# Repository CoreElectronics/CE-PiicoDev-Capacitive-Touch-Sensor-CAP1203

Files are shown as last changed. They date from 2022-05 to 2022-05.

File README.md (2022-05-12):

# PiicoDev® Capacitive Touch Sensor CAP1203

This is the repo for the Core Electronics [PiicoDev Capacitive Touch Sensor CAP1203](https://core-electronics.com.au/catalog/product/view/sku/CE07816).

PiicoDev Capacitive Touch Sensor by Core Electronics

The PiicoDev® Capacitive Touch Sensor gives your project three touch pads to use as inputs. This is an effective way to introduce control inputs to your project.  Get creative and use other items as touch plates using PCB headers or the alligator clip connection holes.

- 3 Capacitive Touch Sensor inputs
- Supports simultaneous touch events
- Programmable sensitivity
- Automatically calibrates at powerup
- Activity LED shows interrupt events
- PiicoDev connector, compatible with Qwiic and STEMMA QT (3.3V only)
- 2.54mm breakout for breadboarding/prototyping
- Manufactured and supported in Australia by Core Electronics

Getting Started Guides

- For [Micro:bit](https://core-electronics.com.au/tutorials/raspberry-pi-pico/piicodev-capacitive-touch-sensor-cap1203-micro-bit-guide.html)
- For [Raspberry Pi Pico](https://core-electronics.com.au/tutorials/raspberry-pi-pico/piicodev-capacitive-touch-sensor-cap1203-raspberry-pi-pico-guide.html)
- For [Raspberry Pi](https://core-electronics.com.au/tutorials/raspberry-pi-pico/piicodev-capacitive-touch-sensor-cap1203-raspberry-pi-guide.html)

# License
This project is open source - please review the LICENSE.md file for further licensing information.

If you have any technical questions, or concerns about licensing, please contact technical support on the [Core Electronics forums](https://forum.core-electronics.com.au/).

# Attribution
The hardware design of this module is influenced by the design from [Sparkfun](https://github.com/sparkfun/Qwiic_Capacitive_Touch_Slider_CAP1203).

*\"PiicoDev\" and the PiicoDev logo are trademarks of Core Electronics Pty Ltd.*

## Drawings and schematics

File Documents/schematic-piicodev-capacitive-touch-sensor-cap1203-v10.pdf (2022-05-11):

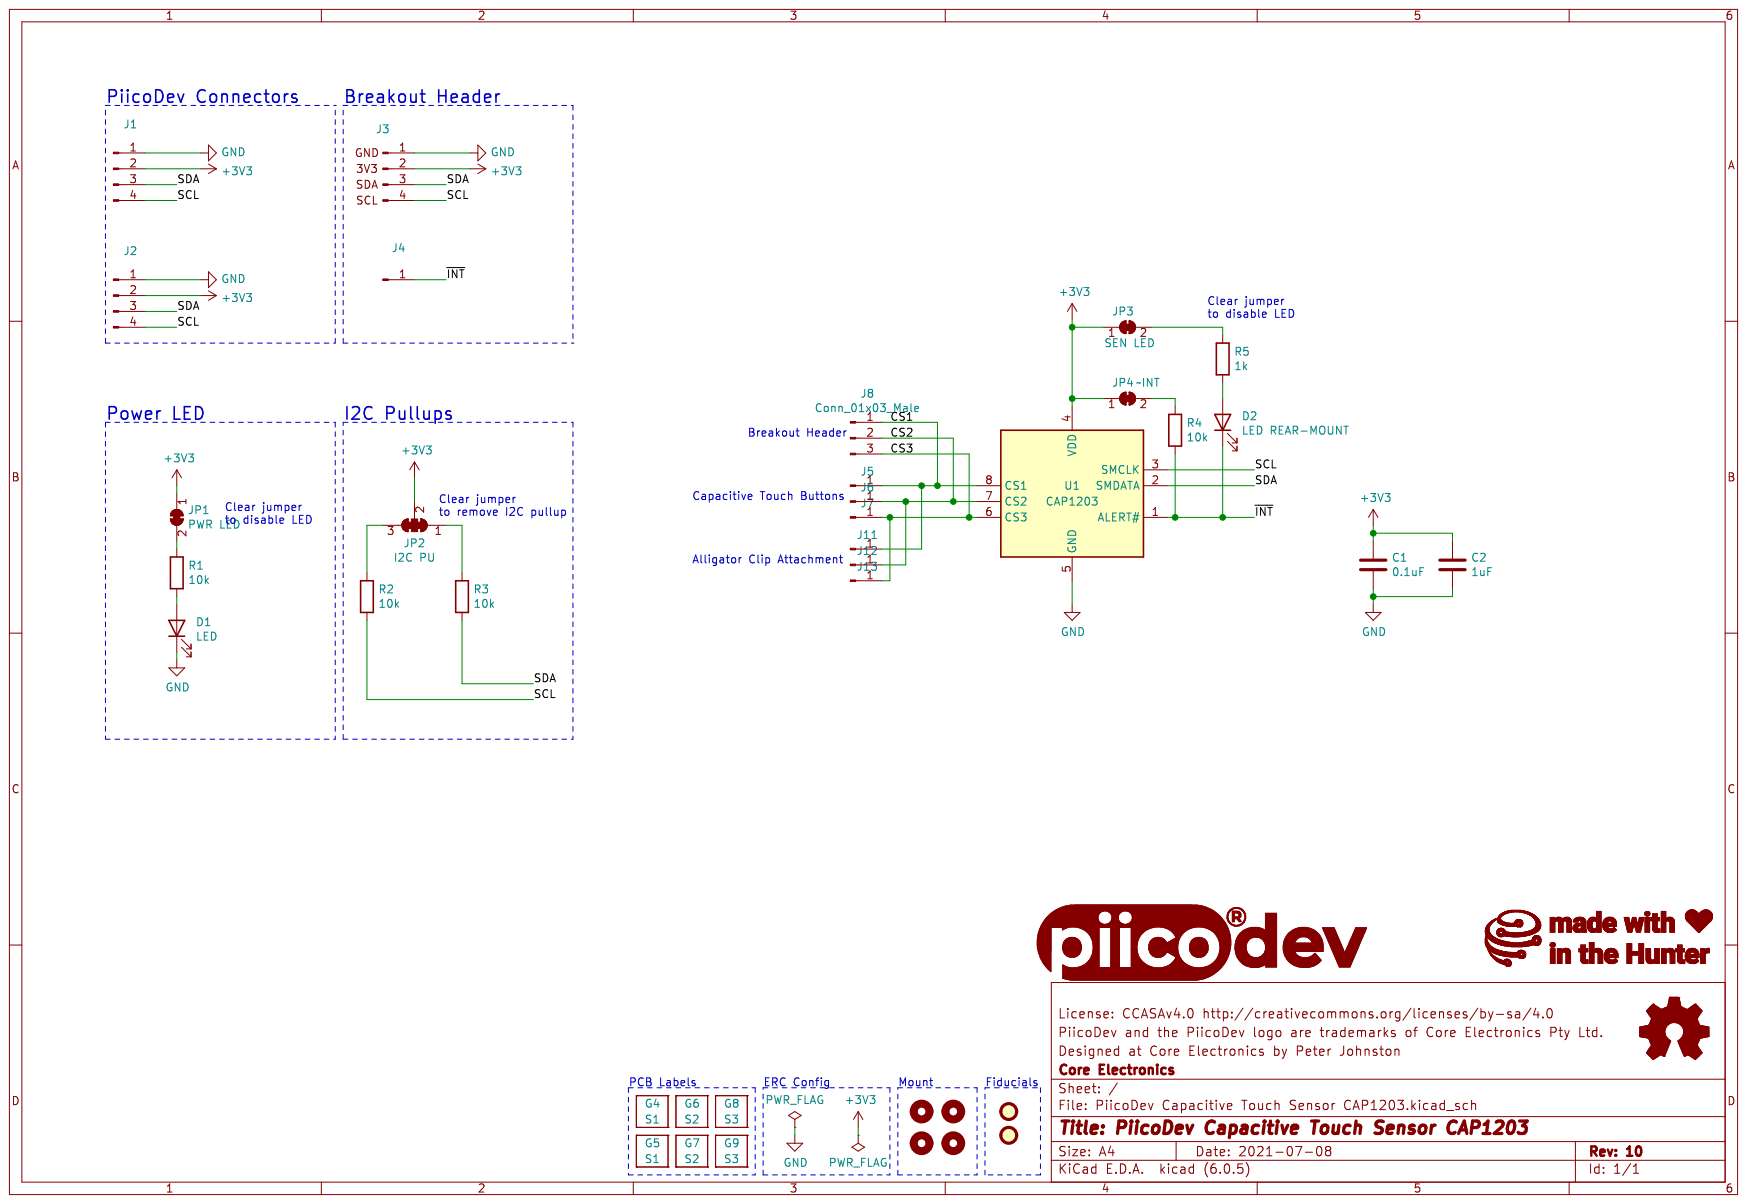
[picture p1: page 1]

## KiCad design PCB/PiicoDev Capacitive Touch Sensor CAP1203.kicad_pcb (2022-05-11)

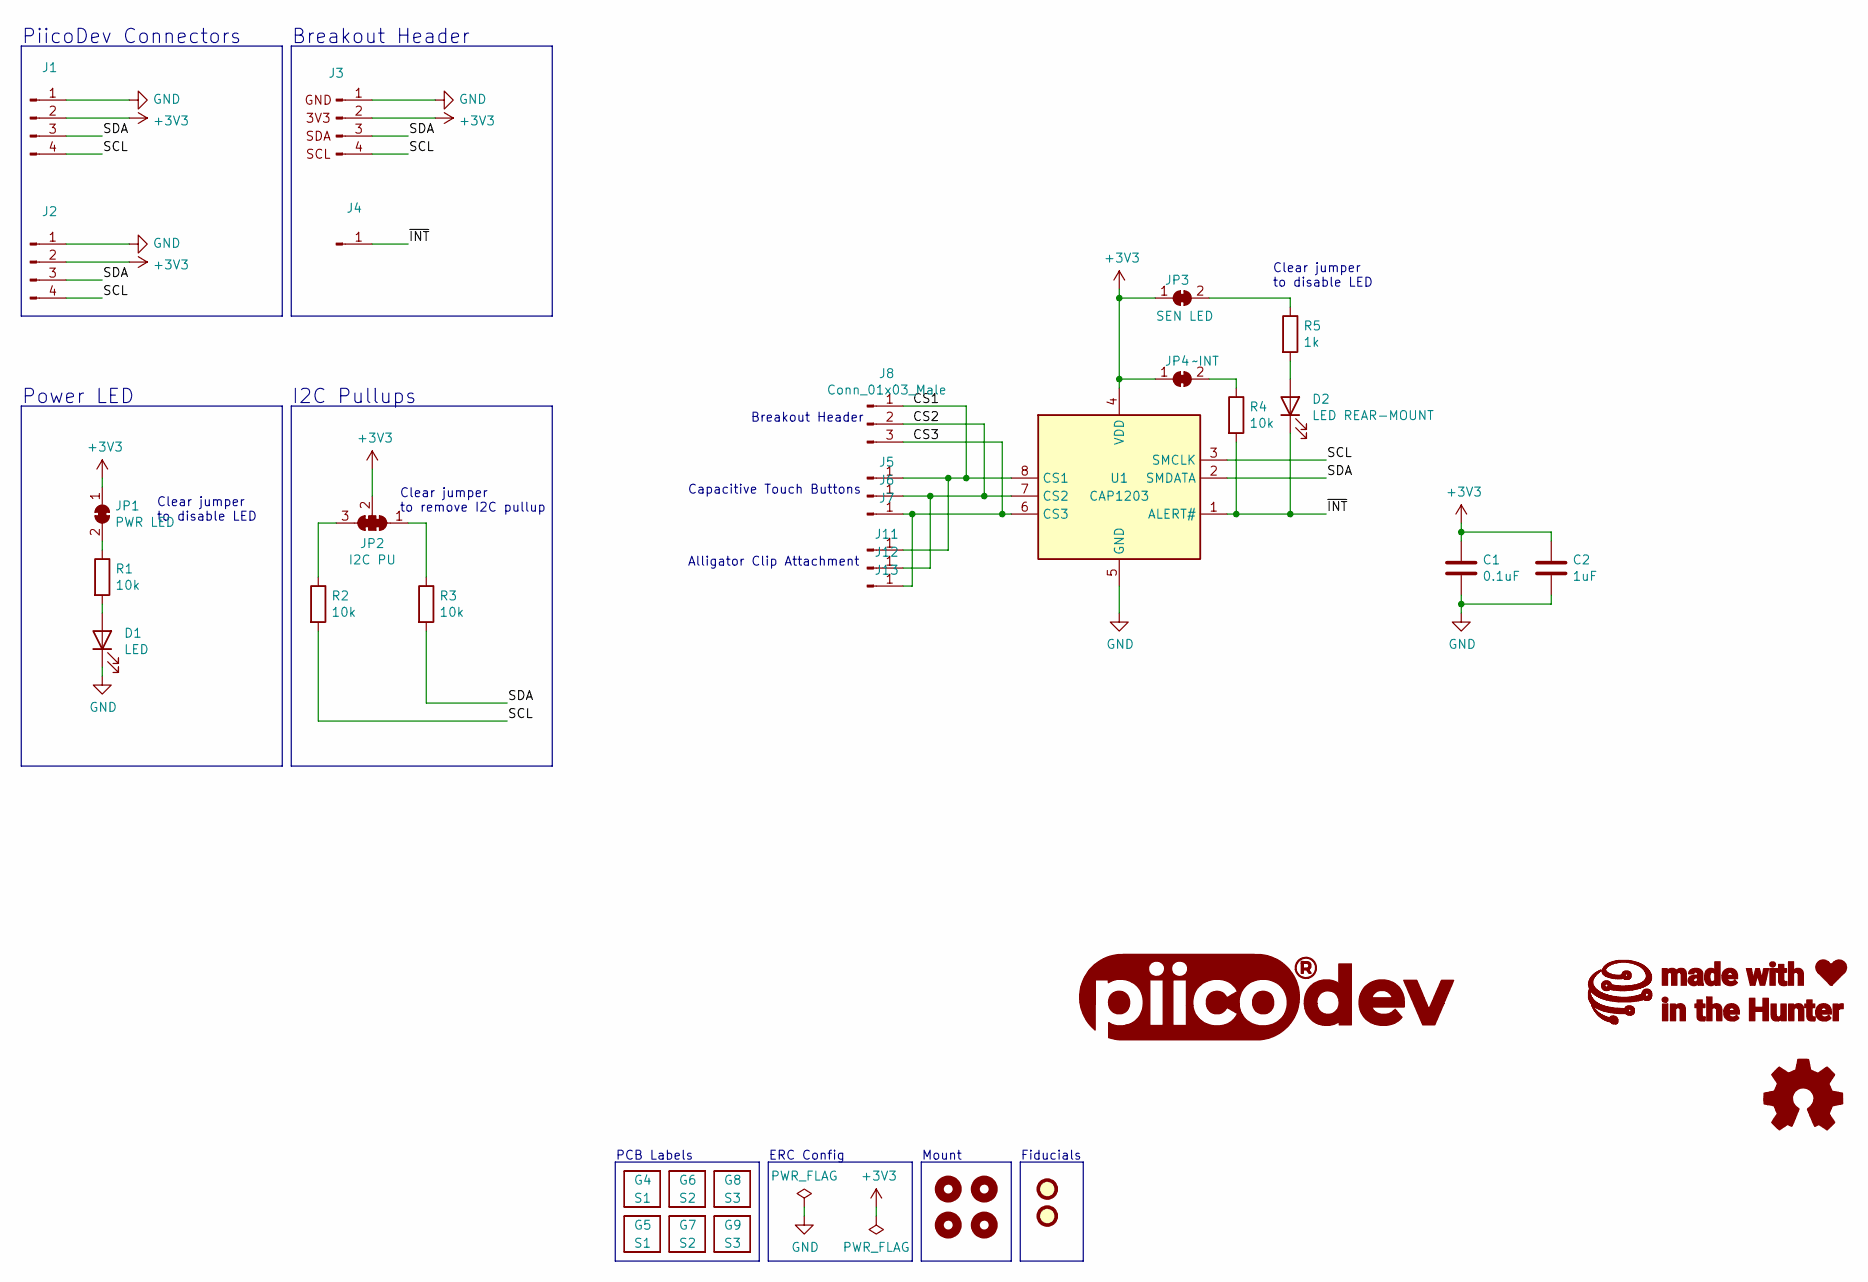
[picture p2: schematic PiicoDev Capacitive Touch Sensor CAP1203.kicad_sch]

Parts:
C1: 0.1uF; C_0402_1005Metric
C2: 1uF; C_0402_1005Metric
D1: LED; LED_0603_1608Metric
D2: LED REAR-MOUNT; LED_1206_3216Metric_ReverseMount_Hole1.8x2.4mm
FID1, FID2: Fiducial; Fiducial_1mm_Mask2mm
G1: LOGO_PiicoDev; piicodev_logo_14.2x3.4mm
G2: LOGO_CoreElectronics_no-text; CoreElectronics_logo_5mm
G3: LOGO_made-with-love; piicodev_logo_14.2x3.4mm
G4, G5: S1; Label_S1_Reverse
G6, G7: S2; Label_S2_Reverse
G8, G9: S3; Label_S3_Reverse
H1, H2, H3, H4: MountingHole; MountingHole_2.7mm_M2.5_PadClearance_1.2
J1, J2: JST_SH_SM04B-SRSS-TB_1x04-1MP_P1.00mm_Horizontal
J3: Conn_PiicoDev_header_01x04_Male; PiicoDev_header_4pin
J4: Conn_01x01_Male; PiicoDev_header_1pin_INT_inverted
J5, J6, J7: Conn_01x01_Male; Capacitive_Touch_Button
J8: Conn_01x03_Male; PinHeader_1x03_P2.54mm_Vertical
J11, J12, J13: Conn_01x01_Male; Conn_alligator
JP1: PWR LED; SolderJumper-2_P1.3mm_Bridged_RoundedPad1.0x1.5mm
JP2: I2C PU; SolderJumper-3_P1.3mm_Closed_RoundedPad1.0x1.5mm_NumberLabe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
JP3: SEN LED; SolderJumper-2_P1.3mm_Bridged_RoundedPad1.0x1.5mm
JP4: ~INT; SolderJumper-2_P1.3mm_Bridged_RoundedPad1.0x1.5mm
LOGO1: Logo_Open_Hardware_Small; oshw
R1, R2, R3, R4: 10k; R_0402_1005Metric
R5: 1k; R_0402_1005Metric
U1: CAP1203; SOIC-8_3.9x4.9mm_P1.27mm

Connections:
+3V3: C1.1, C2.1, J1.2, J2.2, J3.2, JP1.1 (A), JP2.2 (C), JP3.1 (A), JP4.1 (A), U1.4 (VDD)
/CS1: J5.1, J8.1, J11.1, U1.8 (CS1)
/CS2: J6.1, J8.2, J12.1, U1.7 (CS2)
/CS3: J7.1, J8.3, J13.1, U1.6 (CS3)
/SCL: J1.4, J2.4, J3.4, R2.2, U1.3 (SMCLK)
/SDA: J1.3, J2.3, J3.3, R3.2, U1.2 (SMDATA)
/~INT: D2.1 (K), J4.1, R4.2, U1.1 (ALERT#)
GND: C1.2, C2.2, D1.1 (K), J1.1, J2.1, J3.1, U1.5 (GND)
unnamed: D1.2 (A), R1.2
unnamed: D2.2 (A), R5.2
unnamed: JP1.2 (B), R1.1
unnamed: JP2.1 (A), R3.1
unnamed: JP2.3 (B), R2.1
unnamed: JP3.2 (B), R5.1
unnamed: JP4.2 (B), R4.1

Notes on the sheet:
Power LED
I2C Pullups
Capacitive Touch Buttons
Clear jumper to remove I2C pullup
Breakout Header
Alligator Clip Attachment
ERC Config
Mount
PCB Labels
PiicoDev Connectors
Clear jumper to disable LED
Fiducials

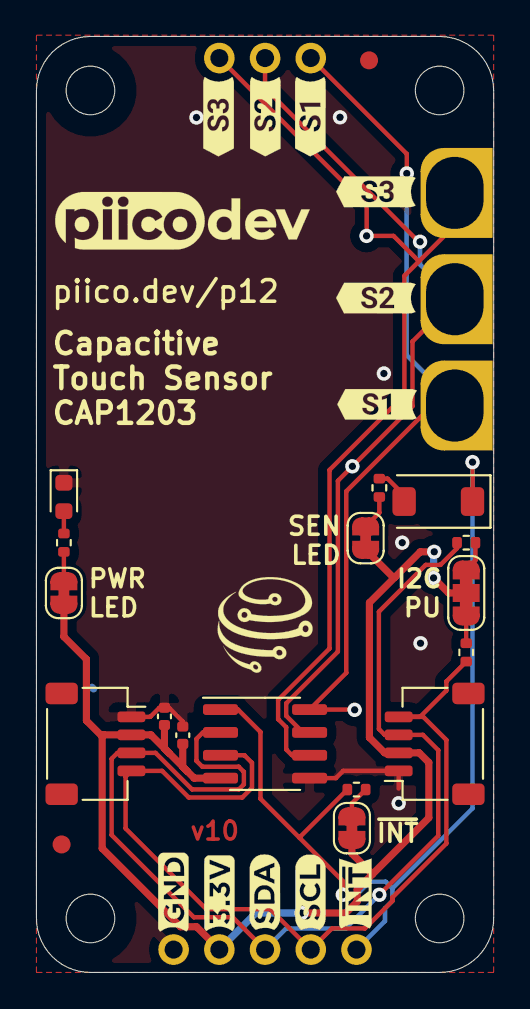
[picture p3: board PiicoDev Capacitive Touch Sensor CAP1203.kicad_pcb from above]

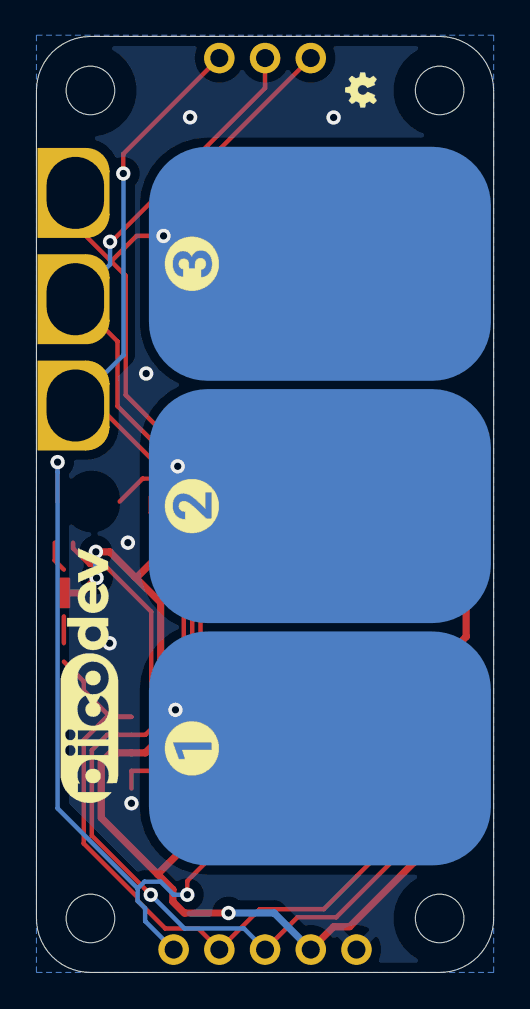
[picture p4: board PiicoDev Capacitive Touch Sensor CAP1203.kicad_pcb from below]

Board: 2 copper layers, 25.4 x 52.0 mm, 41 parts (7 on the bottom side), 15 nets.

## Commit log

2021-06-09 Update interrupt LED and increase alligator clip hole size
    [PiicoDev Capacitive Touch Sensor CAP1203.kicad_pcb, PiicoDev Capacitive Touch Sensor CAP1203.sch]
2021-06-21 Add silk screen labels
    [PiicoDev Capacitive Touch Sensor CAP1203.kicad_pcb, PiicoDev Capacitive Touch Sensor CAP1203.sch]
2021-06-23 Increase Alligator Clip Size
    [PiicoDev Capacitive Touch Sensor CAP1203.kicad_pcb, PiicoDev Capacitive Touch Sensor CAP1203.sch]
2021-06-24 Change top copper fill from grounded to floating sections
    [PiicoDev Capacitive Touch Sensor CAP1203.kicad_pcb, PiicoDev Capacitive Touch Sensor CAP1203.sch]
2021-07-08 Revert "Change top copper fill from grounded to floating sections"
    This reverts commit 368bc0d4ff66a5d992a58d852e4a1f950c0b97f4.
    [PiicoDev Capacitive Touch Sensor CAP1203.kicad_pcb, PiicoDev Capacitive Touch Sensor CAP1203.sch]
2021-07-08 Update version number for production
    [PiicoDev Capacitive Touch Sensor CAP1203.kicad_pcb, PiicoDev Capacitive Touch Sensor CAP1203.sch]
2021-08-24 Change R1 resistor value
    [PiicoDev Capacitive Touch Sensor CAP1203.sch]
2021-12-08 Update R1,2,3,4 to 10k
    [PiicoDev Capacitive Touch Sensor CAP1203.kicad_pcb, PiicoDev Capacitive Touch Sensor CAP1203.sch]
2022-01-25 Update user drawings - dimensioning
    [PiicoDev Capacitive Touch Sensor CAP1203.kicad_pcb]
2022-03-21 Update schematic-piicodev-capacitive-touch-sensor-cap1203-v10.pdf
    resistors 4k7 to 10k
2022-05-11 Upgrade to KiCad 6.0.5
    [PiicoDev Capacitive Touch Sensor CAP1203.kicad_pcb, PiicoDev Capacitive Touch Sensor CAP1203.kicad_sch, PiicoDev Capacitive Touch Sensor CAP1203.sch]
2022-05-11 upgrade to KiCad6

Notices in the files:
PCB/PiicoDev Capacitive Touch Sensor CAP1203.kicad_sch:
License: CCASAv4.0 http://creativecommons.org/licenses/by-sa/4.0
